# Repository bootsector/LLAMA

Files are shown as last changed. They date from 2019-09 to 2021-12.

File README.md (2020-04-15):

**LLAMA - Low Lag Amazing MiSTer Adapter**

This is an open-source / open-hardware controllers adapter for MiSTer FPGA.

Supported outputs are both USB (XInput) and MiSTer's [LLAPI](https://github.com/Kitrinx/LLAPI/blob/master/LLIO.sv) interface.

32U4 module designs include gerber files and SeeedStudio BOM file for Fusion
PCB Assembly service.

LLAMA currently supports original controllers for the systems below:

- Neo Geo / Neo Geo CD (**NOT compatible with SuperGun DB15 based controllers** )
- Super NES
- NES
- TurboGrafx-16 / PC Engine
- Sega Saturn
- Sega Genesis / Master System / Atari 2600 and compatibles

**Latency Measurements - 1000Hz USB polling mode**
| Controller | Samples | Average | Max | Min | Std Dev |
| --- | --- | --- | ---| ----- | --- |
| LLAMA USB  | 2000 |1.6996ms |2.224ms  |1.188ms| 0.289ms

**Button Mapping**

It's possible to map buttons for each supported joystick. Button mapping is done
based on an index that maps to buttons of the internal abstract pad 
(XInput-like).

Mapping is fully customized by the user. Planning your mapping can be done with
the help of the mapper/LLAMA Mapping.xlsx spreadsheet. Change the buttons of
the supported pads in the "Input" area by selecting them from list boxes. You
can see how those mappings affect output for XInput (USB) and also LLAPI cores
by checking the "Output" area of the spreadsheet.

After setting the mappings in the spreadsheet, simply use the numbers inside
parenthesis for each button of each controller in the ```<profile>``` section of
the mapper/map.xml file. There are two profiles per controller. You just
apply the numbers at the same order they read from the spreadsheet to the
chosen controller profile.

After finishing the changes inside mapper/map.xml file, run the 
mapper/mapper.py application (tested only on Python 2.7). 

```
cd mapper
python mapper.py
```

You should probably
need to install intelhex package via pip beforehand.

```pip install intelhex```

The above will convert map.xml to a file named map.eep. This should be 
flashed into AVR's EEPROM like this:

```dfu-programmer atmega32u4 flash --eeprom map.eep --force```

Mapping is not mandatory. The firmware will save the defaults to EEPROM by
itself the first time it runs if no valid mapping/config is found.

Each controller has two mapping profiles. Below you can find the button
combination on each controller that will switch mapping profiles:

NeoGeo: Down + Start + B

NES: Down + Start + A

SNES: Down + Start + A

Saturn: Down + Start + C

TG16/PCE: Down + Start + I

Genesis: Down + Start + C

**Licensing:**

- Firmware and bootloader sources are licensed under [GPL-3.0](LICENSE)
- PCBs are licensed under [CC BY-NC-SA 4.0](pcb/LICENSE.txt)

**Disclaimer:**

The firmware source code made available here is an original creation by Bruno 
Freitas. 

The AVR ASM/C implementation of the LLAPI "slave" interface presented here
was created from scratch by Bruno Freitas. MiSTer's LLAPI "master" interface
protocol described [here](https://github.com/Kitrinx/LLAPI/blob/master/LLIO.sv) 
in SystemVerilog has been used as documentation and reference only.

No source code from third parties has been used used by this project.

No reverse-engineering has been done against commercial and non-commercial
products during the development of this project.

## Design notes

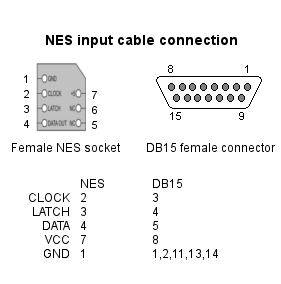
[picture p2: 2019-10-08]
docs/cables/nes.png

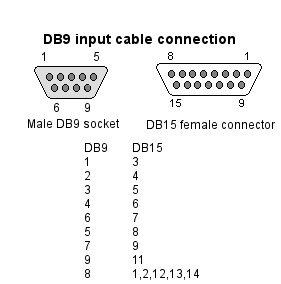
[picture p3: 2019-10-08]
docs/cables/db9.png

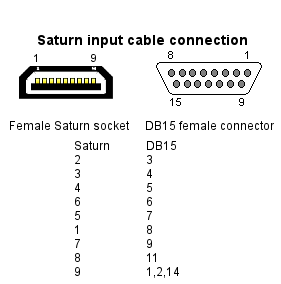
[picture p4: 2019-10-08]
docs/cables/saturn.png

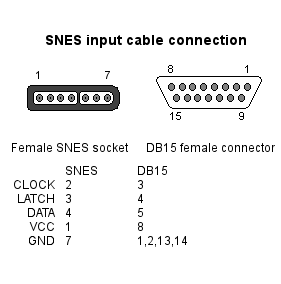
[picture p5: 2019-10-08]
docs/cables/snes.png

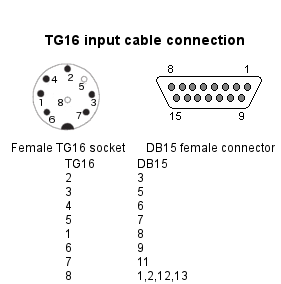
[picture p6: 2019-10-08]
docs/cables/tg16.png

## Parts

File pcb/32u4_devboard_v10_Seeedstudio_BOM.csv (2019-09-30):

Parts | OPL SKU | Qty
C1,C6,C7,C9 | 302010165 | 4
R1,R5 | 301010361 | 2
C8 | 302020011 | 1
XTAL | 306010037 | 1
C2,C3 | 302010143 | 2
R4 | 301010311 | 1
C4 | 302010179 | 1
R2,R3 | 301010329 | 2
32U4-AU | 310010010 | 1
F1 | 307010002 | 1
Led | 304090046 | 1
USB | 320010014 | 1

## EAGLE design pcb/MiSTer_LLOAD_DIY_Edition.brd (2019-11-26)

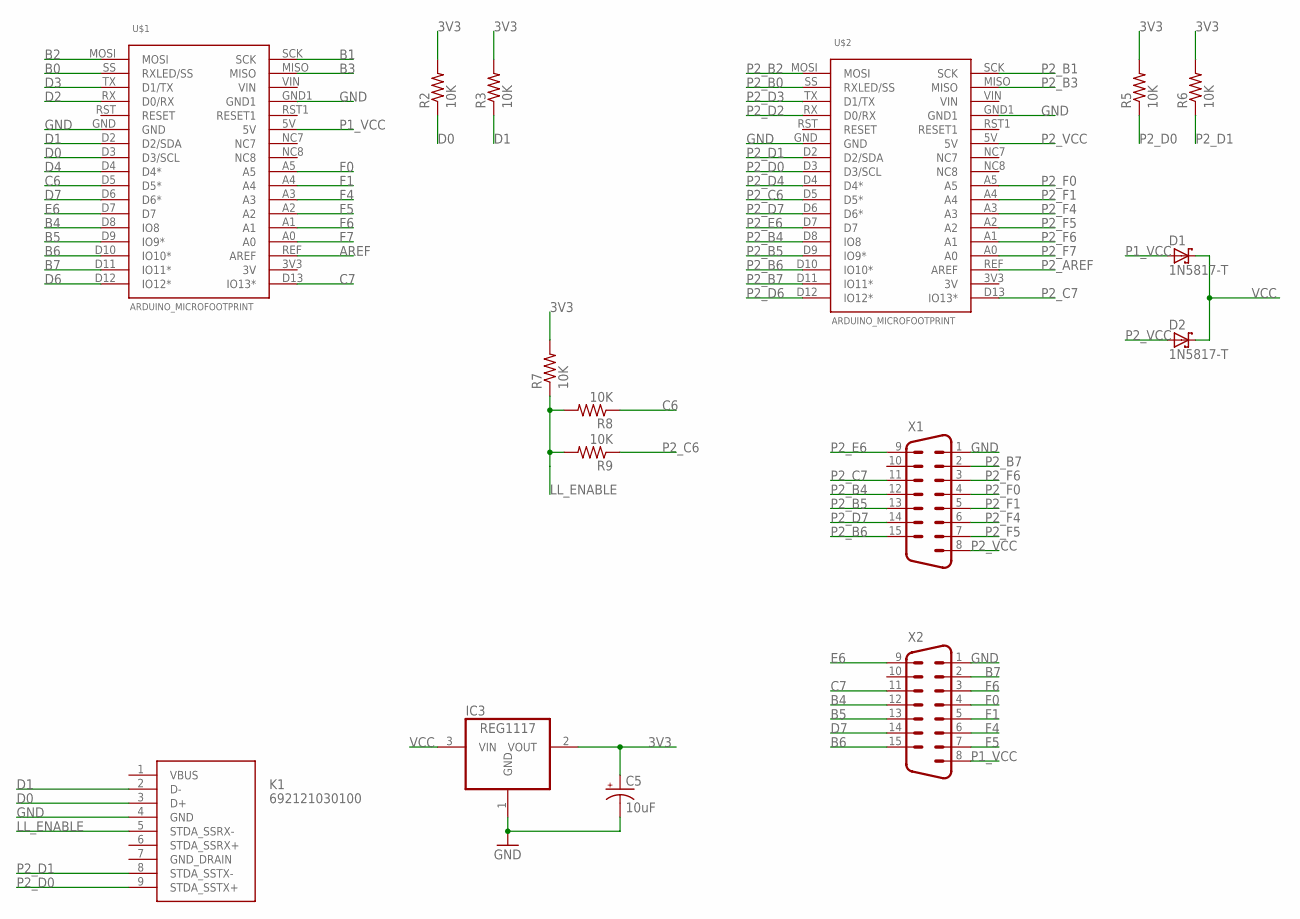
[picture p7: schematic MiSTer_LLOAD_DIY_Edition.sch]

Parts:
C5: 10uF; E2,5-6
D1, D2: 1N5817-T; DO41-7.6
IC3: REG1117; SOT223
K1: 692121030100
R2, R3, R5, R6, R7, R8, R9: 10K; 0207/10
U$1, U$2: ARDUINO_MICROFOOTPRINT; ARDUINO-MICRO
X1, X2: M15HP

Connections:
3V3: C5.+, IC3.2 (VOUT), R2.2, R3.2, R5.2, R6.2, R7.2
AREF: U$1.REF (AREF)
B0: U$1.SS (RXLED/SS)
B1: U$1.SCK
B2: U$1.MOSI
B3: U$1.MISO
B4: U$1.D8 (IO8), X2.12
B5: U$1.D9 (IO9*), X2.13
B6: U$1.D10 (IO10*), X2.15
B7: U$1.D11 (IO11*), X2.2
C6: R8.1, U$1.D5 (D5*)
C7: U$1.D13 (IO13*), X2.11
D0: K1.3 (D+), R2.1, U$1.D3 (D3/SCL)
D1: K1.2 (D-), R3.1, U$1.D2 (D2/SDA)
D2: U$1.RX (D0/RX)
D3: U$1.TX (D1/TX)
D4: U$1.D4 (D4*)
D6: U$1.D12 (IO12*)
D7: U$1.D6 (D6*), X2.14
E6: U$1.D7, X2.9
F0: U$1.A5, X2.4
F1: U$1.A4, X2.5
F4: U$1.A3, X2.6
F5: U$1.A2, X2.7
F6: U$1.A1, X2.3
F7: U$1.A0
GND: C5.-, IC3.1 (GND), K1.4 (GND), U$1.GND, U$1.GND1, U$2.GND, U$2.GND1, X1.1, X2.1
LL_ENABLE: K1.5 (STDA_SSRX-), R7.1, R8.2, R9.2
P1_VCC: D1.A, U$1.5V, X2.8
P2_AREF: U$2.REF (AREF)
P2_B0: U$2.SS (RXLED/SS)
P2_B1: U$2.SCK
P2_B2: U$2.MOSI
P2_B3: U$2.MISO
P2_B4: U$2.D8 (IO8), X1.12
P2_B5: U$2.D9 (IO9*), X1.13
P2_B6: U$2.D10 (IO10*), X1.15
P2_B7: U$2.D11 (IO11*), X1.2
P2_C6: R9.1, U$2.D5 (D5*)
P2_C7: U$2.D13 (IO13*), X1.11
P2_D0: K1.9 (STDA_SSTX+), R5.1, U$2.D3 (D3/SCL)
P2_D1: K1.8 (STDA_SSTX-), R6.1, U$2.D2 (D2/SDA)
P2_D2: U$2.RX (D0/RX)
P2_D3: U$2.TX (D1/TX)
P2_D4: U$2.D4 (D4*)
P2_D6: U$2.D12 (IO12*)
P2_D7: U$2.D6 (D6*), X1.14
P2_E6: U$2.D7, X1.9
P2_F0: U$2.A5, X1.4
P2_F1: U$2.A4, X1.5
P2_F4: U$2.A3, X1.6
P2_F5: U$2.A2, X1.7
P2_F6: U$2.A1, X1.3
P2_F7: U$2.A0
P2_VCC: D2.A, U$2.5V, X1.8
VCC: D1.C, D2.C, IC3.3 (VIN)

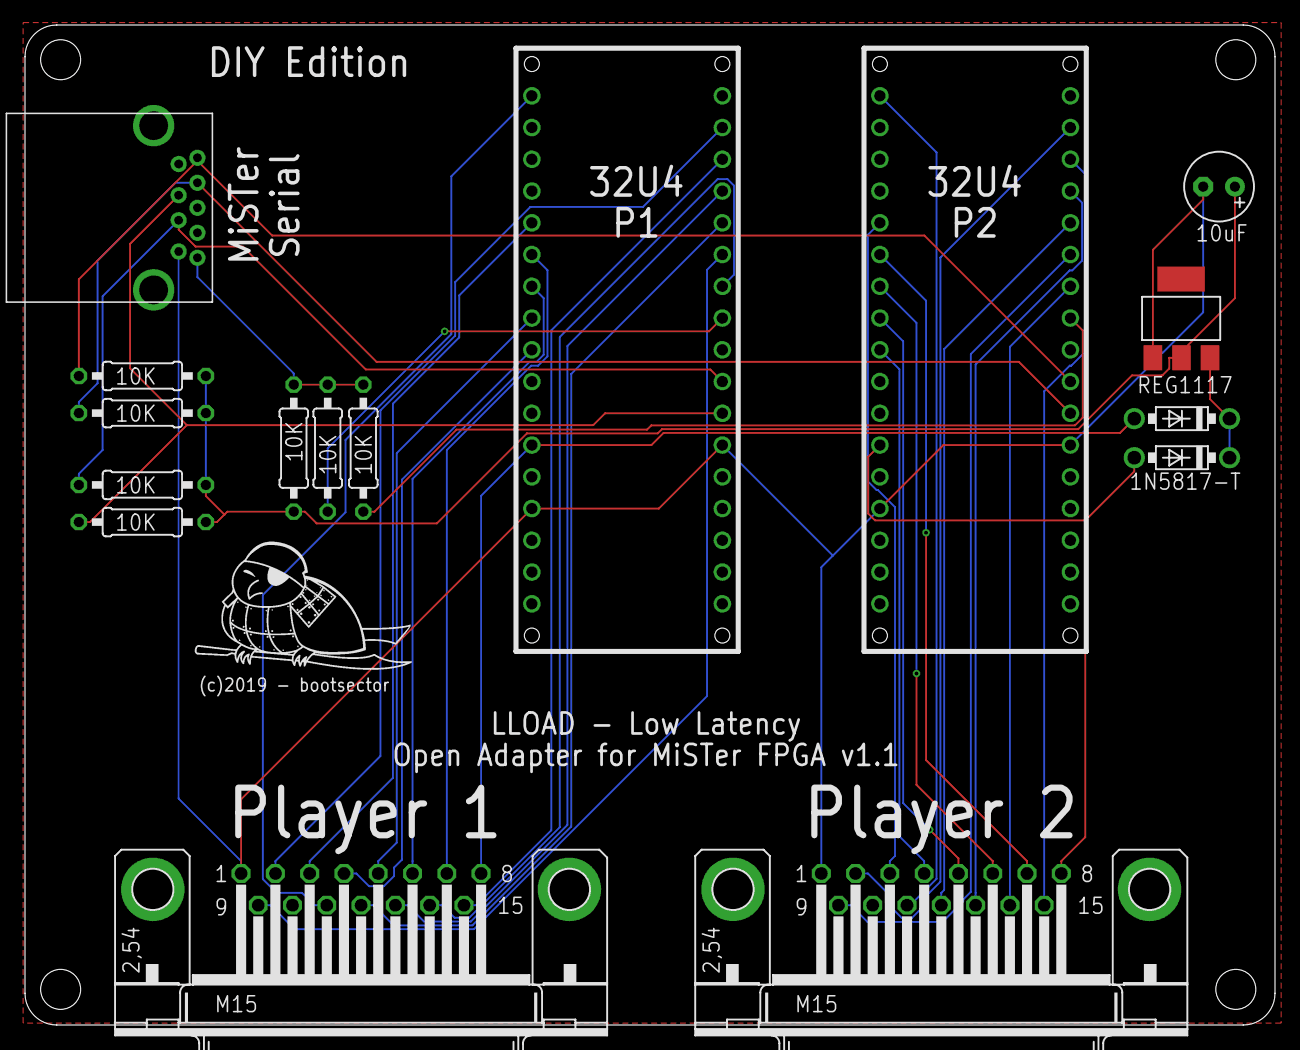
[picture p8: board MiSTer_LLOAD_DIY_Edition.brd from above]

Board: 2 copper layers, 100.0 x 80.0 mm, 16 parts (0 on the bottom side), 36 nets.

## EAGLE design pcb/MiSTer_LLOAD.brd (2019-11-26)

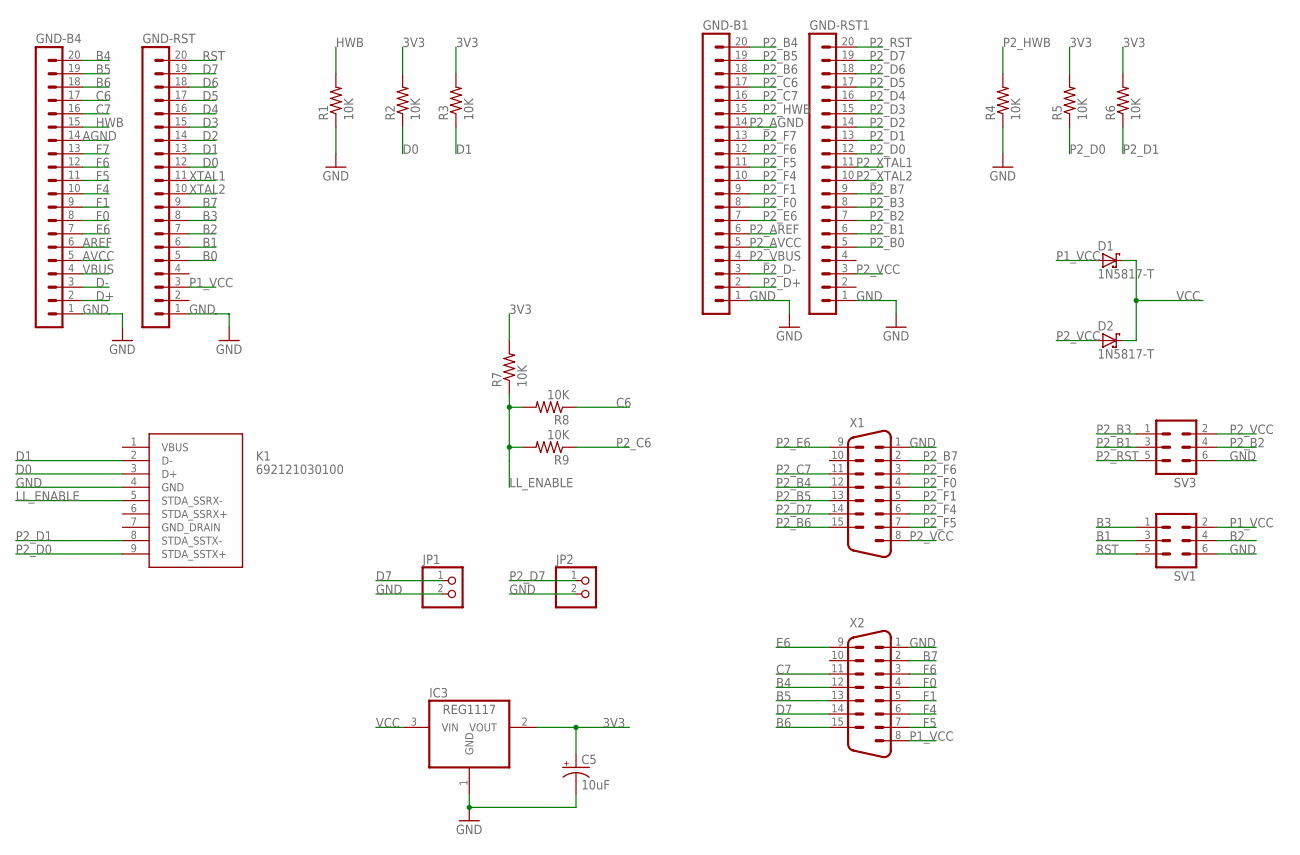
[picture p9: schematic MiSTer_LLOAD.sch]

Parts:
C5: 10uF; E2,5-6
D1, D2: 1N5817-T; DO41-7.6
GND-B1, GND-B4: MA20-1
GND-RST, GND-RST1: MA20-1
IC3: REG1117; SOT223
JP1, JP2: PINHD-1X2; 1X02
K1: 692121030100
R1, R2, R3, R4, R5, R6, R7, R8, R9: 10K; 0207/10
SV1, SV3: MA03-2
X1, X2: M15HP

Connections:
3V3: C5.+, IC3.2 (VOUT), R2.2, R3.2, R5.2, R6.2, R7.2
AGND: GND-B4.14
AREF: GND-B4.6
AVCC: GND-B4.5
B0: GND-RST.5
B1: GND-RST.6, SV1.3
B2: GND-RST.7, SV1.4
B3: GND-RST.8, SV1.1
B4: GND-B4.20, X2.12
B5: GND-B4.19, X2.13
B6: GND-B4.18, X2.15
B7: GND-RST.9, X2.2
C6: GND-B4.17, R8.1
C7: GND-B4.16, X2.11
D0: GND-RST.12, K1.3 (D+), R2.1
D1: GND-RST.13, K1.2 (D-), R3.1
D2: GND-RST.14
D3: GND-RST.15
D4: GND-RST.16
D5: GND-RST.17
D6: GND-RST.18
D7: GND-RST.19, JP1.1, X2.14
D+: GND-B4.2
D-: GND-B4.3
E6: GND-B4.7, X2.9
F0: GND-B4.8, X2.4
F1: GND-B4.9, X2.5
F4: GND-B4.10, X2.6
F5: GND-B4.11, X2.7
F6: GND-B4.12, X2.3
F7: GND-B4.13
GND: C5.-, GND-B1.1, GND-B4.1, GND-RST.1, GND-RST1.1, IC3.1 (GND), JP1.2, JP2.2, K1.4 (GND), R1.1, R4.1, SV1.6, SV3.6, X1.1, X2.1
HWB: GND-B4.15, R1.2
LL_ENABLE: K1.5 (STDA_SSRX-), R7.1, R8.2, R9.2
P1_VCC: D1.A, GND-RST.3, SV1.2, X2.8
P2_AGND: GND-B1.14
P2_AREF: GND-B1.6
P2_AVCC: GND-B1.5
P2_B0: GND-RST1.5
P2_B1: GND-RST1.6, SV3.3
P2_B2: GND-RST1.7, SV3.4
P2_B3: GND-RST1.8, SV3.1
P2_B4: GND-B1.20, X1.12
P2_B5: GND-B1.19, X1.13
P2_B6: GND-B1.18, X1.15
P2_B7: GND-RST1.9, X1.2
P2_C6: GND-B1.17, R9.1
P2_C7: GND-B1.16, X1.11
P2_D0: GND-RST1.12, K1.9 (STDA_SSTX+), R5.1
P2_D1: GND-RST1.13, K1.8 (STDA_SSTX-), R6.1
P2_D2: GND-RST1.14
P2_D3: GND-RST1.15
P2_D4: GND-RST1.16
P2_D5: GND-RST1.17
P2_D6: GND-RST1.18
P2_D7: GND-RST1.19, JP2.1, X1.14
P2_D+: GND-B1.2
P2_D-: GND-B1.3
P2_E6: GND-B1.7, X1.9
P2_F0: GND-B1.8, X1.4
P2_F1: GND-B1.9, X1.5
P2_F4: GND-B1.10, X1.6
P2_F5: GND-B1.11, X1.7
P2_F6: GND-B1.12, X1.3
P2_F7: GND-B1.13
P2_HWB: GND-B1.15, R4.2
P2_RST: GND-RST1.20, SV3.5
P2_VBUS: GND-B1.4
P2_VCC: D2.A, GND-RST1.3, SV3.2, X1.8
P2_XTAL1: GND-RST1.11
P2_XTAL2: GND-RST1.10
RST: GND-RST.20, SV1.5
VBUS: GND-B4.4
VCC: D1.C, D2.C, IC3.3 (VIN)
XTAL1: GND-RST.11
XTAL2: GND-RST.10

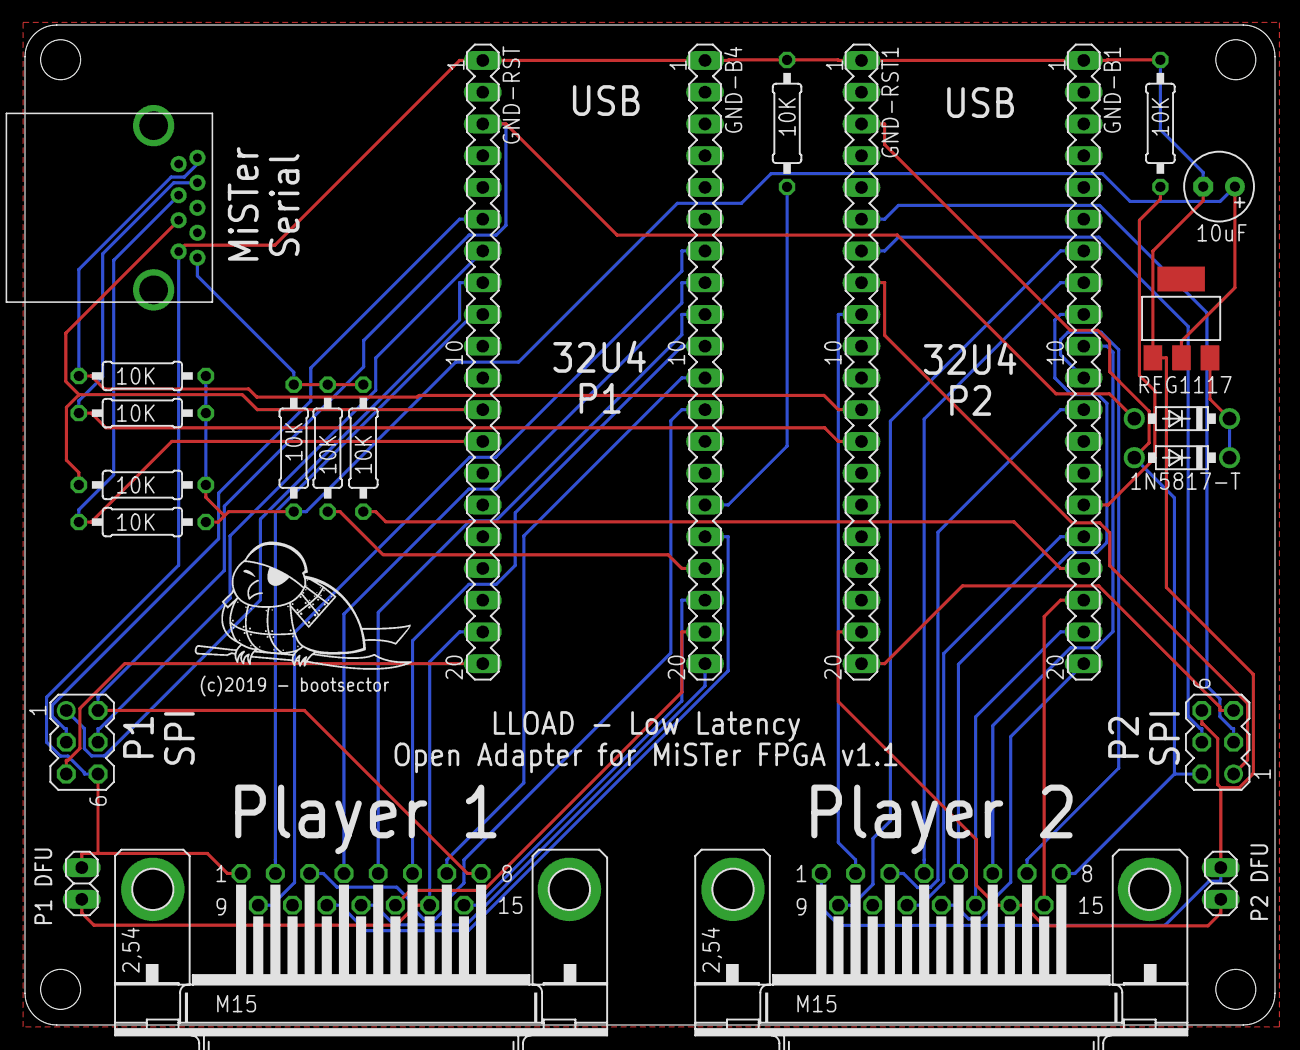
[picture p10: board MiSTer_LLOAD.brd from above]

Board: 2 copper layers, 100.0 x 80.0 mm, 24 parts (0 on the bottom side), 46 nets.

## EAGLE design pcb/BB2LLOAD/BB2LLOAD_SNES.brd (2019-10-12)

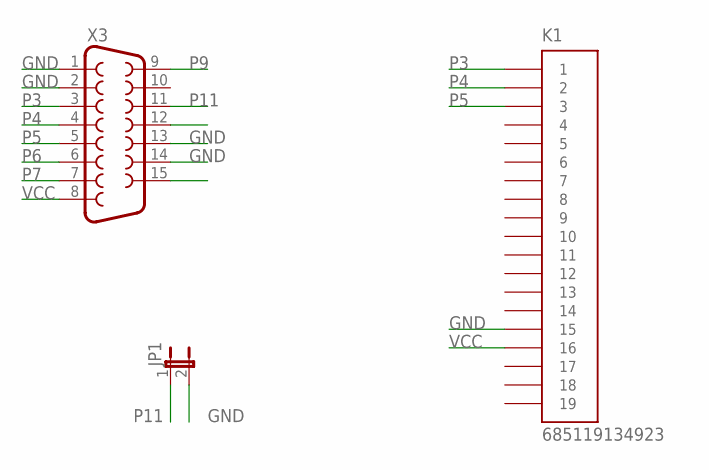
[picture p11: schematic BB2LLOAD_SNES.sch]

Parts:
JP1: JP1E; JP1
K1: 685119134923
X3: F15HP

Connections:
GND: JP1.2, K1.15, X3.1, X3.2, X3.13, X3.14
P3: K1.1, X3.3
P4: K1.2, X3.4
P5: K1.3, X3.5
P6: X3.6
P7: X3.7
P9: X3.9
P11: JP1.1, X3.11
VCC: K1.16, X3.8

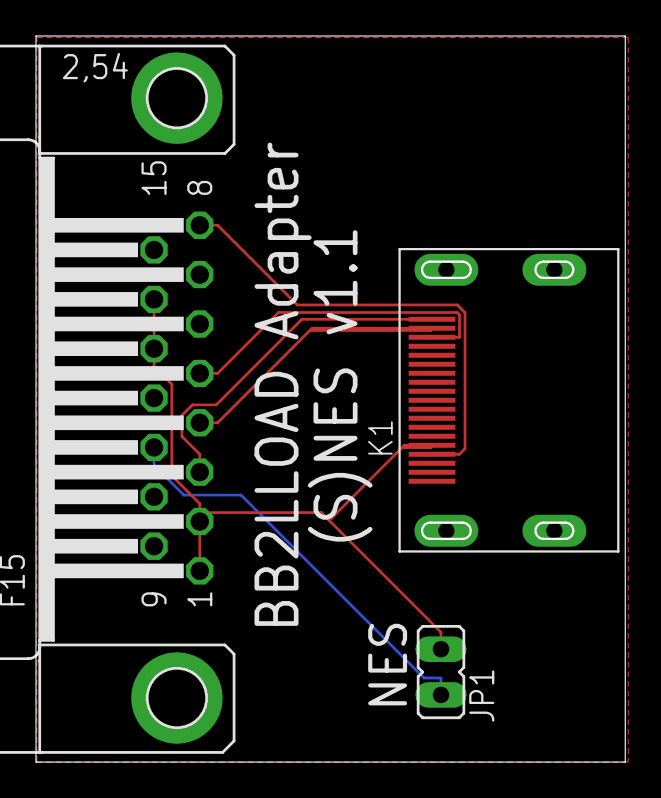
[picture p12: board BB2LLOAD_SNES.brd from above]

Board: 2 copper layers, 32.7 x 40.3 mm, 3 parts (0 on the bottom side), 6 nets.

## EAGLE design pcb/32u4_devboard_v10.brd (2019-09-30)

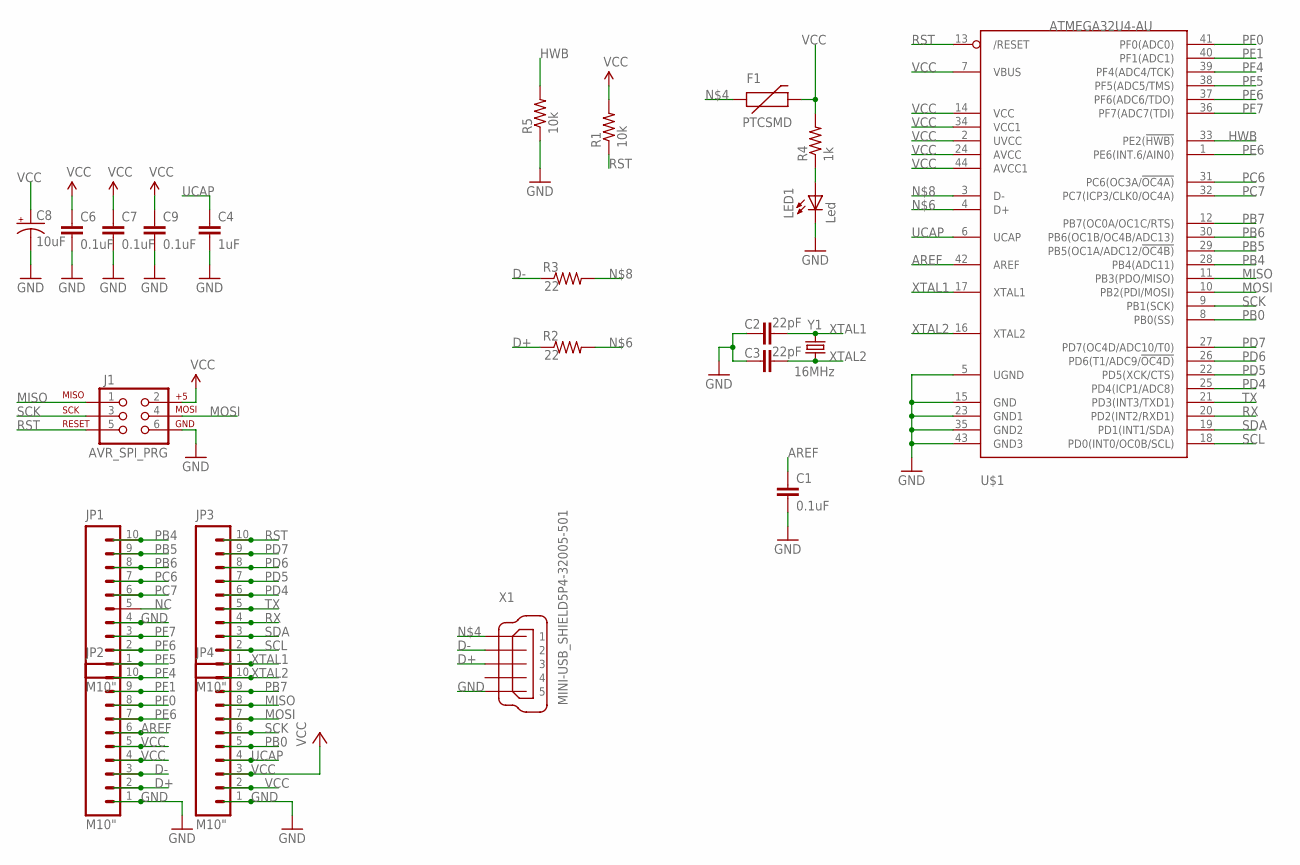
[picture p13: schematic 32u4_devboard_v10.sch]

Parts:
C1, C6, C7, C9: 0.1uF; 0805
C2, C3: 22pF; 0603-CAP
C4: 1uF; 0805
C8: 10uF; EIA3216
F1: PTCSMD; PTC-1206
J1: AVR_SPI_PRG; 2X3
JP1, JP2, JP3, JP4: M10"; 1X10
LED1: Led; CHIP-LED0805
R1, R5: 10k; 0805
R2, R3: 22; 0805
R4: 1k; 0805
U$1: ATMEGA32U4-AU; TQFP44
X1: MINI-USB_SHIELD5P4-32005-501; 32005-501
Y1: 16MHz; HC49US

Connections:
AREF: C1.1, JP2.6, U$1.42 (AREF)
D+: JP2.2, R2.1, X1.3
D-: JP2.3, R3.1, X1.2
GND: C1.2, C2.1, C3.1, C4.2, C6.2, C7.2, C8.C (-), C9.2, J1.6, JP1.4, JP2.1, JP4.1, LED1.C, R5.1, U$1.5 (UGND), U$1.15 (GND), U$1.23 (GND1), U$1.35 (GND2), U$1.43 (GND3), X1.5
HWB: R5.2, U$1.33 (PE2(!HWB))
MISO: J1.1, JP4.8, U$1.11 (PB3(PDO/MISO))
MOSI: J1.4, JP4.7, U$1.10 (PB2(PDI/MOSI))
unnamed: F1.1, X1.1
unnamed: R2.2, U$1.4 (D+)
unnamed: R3.2, U$1.3 (D-)
unnamed: LED1.A, R4.1
NC: JP1.5
PB0: JP4.5, U$1.8 (PB0(SS))
PB4: JP1.10, U$1.28 (PB4(ADC11))
PB5: JP1.9, U$1.29 (PB5(OC1A/ADC12/!OC4B))
PB6: JP1.8, U$1.30 (PB6(OC1B/OC4B/ADC13))
PB7: JP4.9, U$1.12 (PB7(OC0A/OC1C/RTS))
PC6: JP1.7, U$1.31 (PC6(OC3A/!OC4A))
PC7: JP1.6, U$1.32 (PC7(ICP3/CLK0/OC4A))
PD4: JP3.6, U$1.25 (PD4(ICP1/ADC8))
PD5: JP3.7, U$1.22 (PD5(XCK/CTS))
PD6: JP3.8, U$1.26 (PD6(T1/ADC9/!OC4D))
PD7: JP3.9, U$1.27 (PD7(OC4D/ADC10/T0))
PE6: JP2.7, U$1.1 (PE6(INT.6/AIN0))
PF0: JP2.8, U$1.41 (PF0(ADC0))
PF1: JP2.9, U$1.40 (PF1(ADC1))
PF4: JP2.10, U$1.39 (PF4(ADC4/TCK))
PF5: JP1.1, U$1.38 (PF5(ADC5/TMS))
PF6: JP1.2, U$1.37 (PF6(ADC6/TDO))
PF7: JP1.3, U$1.36 (PF7(ADC7(TDI))
RST: J1.5, JP3.10, R1.1, U$1.13 (/RESET)
RX: JP3.4, U$1.20 (PD2(INT2/RXD1))
SCK: J1.3, JP4.6, U$1.9 (PB1(SCK))
SCL: JP3.2, U$1.18 (PD0(INT0/OC0B/SCL))
SDA: JP3.3, U$1.19 (PD1(INT1/SDA))
TX: JP3.5, U$1.21 (PD3(INT3/TXD1))
UCAP: C4.1, JP4.4, U$1.6 (UCAP)
VCC: C6.1, C7.1, C8.A (+), C9.1, F1.2, J1.2, JP2.4, JP2.5, JP4.2, JP4.3, R1.2, R4.2, U$1.2 (UVCC), U$1.7 (VBUS), U$1.14 (VCC), U$1.24 (AVCC), U$1.34 (VCC1), U$1.44 (AVCC1)
XTAL1: C2.2, JP3.1, U$1.17 (XTAL1), Y1.2
XTAL2: C3.2, JP4.10, U$1.16 (XTAL2), Y1.1

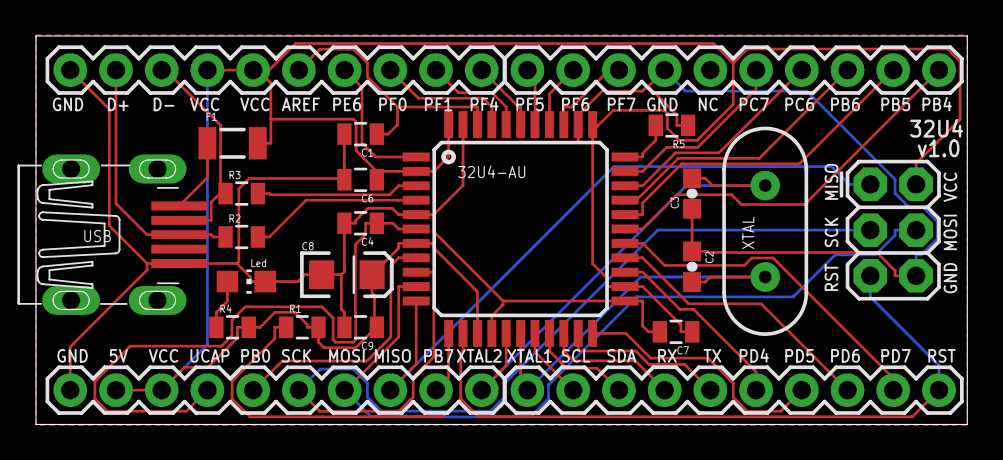
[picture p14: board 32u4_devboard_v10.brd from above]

Board: 2 copper layers, 51.7 x 21.6 mm, 23 parts (0 on the bottom side), 39 nets.

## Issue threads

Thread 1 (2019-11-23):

Supergun pinout risk.

Dubon77, 2019-11-23:
Currently connecting a controller that is wired for connecting to a supergun can not be directly connected to the db15 port and requires an adapter. Neo geo controllers should be fine. This is , afaik, because pin 10 currently is powered and pressing a button connected to it could cause damage to the arduino. Because of this either an adapter, or a revision of the main pcb witch fixes this is required.

bootsector, 2019-11-26:
Pushed new v1.1 revision. This is still not compatible with Supergun (although it still works with Neo Geo and Neo Geo CD pads, just like the previous version). I will work on a PCB adapter to allow supergun on this soon.

Closed 2019-11-26.

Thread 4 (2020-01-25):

All controller types share the same USB PID

mathieulh, 2020-01-25:
All controller types share the same USB PID, this causes issues when mapping usb controllers on the MiSTer main menu as mapping one controller overwrites the previous mapping of another as all controllers, regardless of types/number of buttons... are detected as the same controller; using a different PID per controller type would fix this.

Here is an example of 2 LLOAD instances using a SATURN and a SNES controller respectively:

[  409.018380] usb 1-1.7: USB disconnect, device number 8
[  748.401583] usb 1-1.7: new full-speed USB device number 9 using dwc2
[  748.505909] usb 1-1.7: New USB device found, idVendor=045e, idProduct=028e, bcdDevice= 1.14
[  748.505969] usb 1-1.7: New USB device strings: Mfr=1, Product=2, SerialNumber=3
[  748.505977] usb 1-1.7: Product: LLOAD - Low Latency Open Adapter
[  748.505984] usb 1-1.7: Manufacturer: www.brunofreitas.com
[  748.505989] usb 1-1.7: SerialNumber: 1.0
[  748.508384] XPAD: original out.bInterval=1 -> new interval=1
[  748.508393] XPAD: original in.bInterval=1 -> new interval=1
[  748.508856] input: Microsoft X-Box 360 pad as /devices/platform/soc/ffb40000.usb/usb1/1-1/1-1.7/1-1.7:1.0/input/input9

[  876.218384] usb 1-1.2: USB disconnect, device number 3
[  877.681857] usb 1-1.2: new full-speed USB device number 10 using dwc2
[  877.783101] usb 1-1.2: New USB device found, idVendor=045e, idProduct=028e, bcdDevice= 1.14
[  877.783112] usb 1-1.2: New USB device strings: Mfr=1, Product=2, SerialNumber=3
[  877.783119] usb 1-1.2: Product: LLOAD - Low Latency Open Adapter
[  877.783126] usb 1-1.2: Manufacturer: www.brunofreitas.com
[  877.783132] usb 1-1.2: SerialNumber: 1.0
[  877.785749] XPAD: original out.bInterval=1 -> new interval=1
[  877.785758] XPAD: original in.bInterval=1 -> new interval=1
[  877.786275] input: Microsoft X-Box 360 pad as /devices/platform/soc/ffb40000.usb/usb1/1-1/1-1.2/1-1.2:1.0/input/input10

The firmware code would need to be adapted to not use the fixed descriptors found here:

https://github.com/bootsector/LLOAD/blob/master/firmware/Output/USB/Descriptors.c

bootsector, 2020-01-25:
What kind of issues are you having with this? This is by design. Changing PID is not ideal since it will require a USB disconnection/connection every time you change controllers. This is something I don't want LLOAD to have.

mathieulh, 2020-01-26:
The main issue is that MiSTer OSD uses PID to differentiate between controllers, so if you use a genesis  or saturn 6 button controller, map the controls on the MiSTer main menu, then use a SNES controller and map the controls again, finally switch back to your genesis/saturn controllers, buttons used in the OSD won't be the same because the remapping of your SNES controller will have overwritten the mapping configuration for your Genesis/Saturn one.

bootsector, 2020-01-26:
For that you should rely on LLOAD's own pad abstraction default mapping. So, for example, if you map SNES buttons B and A for CANCEL and ENTER respectively, those will be B and C on a Saturn pad (and B and A for a NES pad, and A and B for a NeoGeo CD pad, and so on...)

mathieulh, 2020-01-26:
That's pretty much what I am doing but it is both kind of confusing and annoying, especially to average users who wouldn't understand why their controller configurations keep changing, realistically resetting the usb stack after controller detection would take less than a second and likely be imperceptible to the end user.

bootsector, 2020-02-08:
As discussed previously, I'm closing this because:

1- This behavior is by design

2- LLOAD is a unique USB device. Hence it should have a single VID:PID as per standard

3- There's no "clean" way to change the PID. Also, Windows has issues with some PIDs not issued by Microsoft.

Closed 2020-02-08.

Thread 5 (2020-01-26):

Feature Request:  Ability to rotate button mapping

SegaSnatcher, 2020-01-26:
There is a handy feature within Gamer Pro/Blisster where you can hold 4 face buttons + start and it will rotate the controller mapping.   So say you want to use a SNES controller on GBA core via LLAPI, but don't like having to use the B and A buttons, you simply hold 4 buttons + Start for a few seconds and it will rotate the mapping so that Y functions as the B button and B functions as the A button.  This makes playing GBA with a SNES controller much more enjoyable.

bootsector, 2020-01-26:
In order to keep consistency with what MiSTer already provides for USB controllers, best approach would be adding mapping capabilities inside LLAPI cores. More logic added to the controller adapter, more lag we get.
In case LLAPI input mapping is not under anyone's roadmap, I will think about some simple input profiles switching in the future. No ETA on this, though.

bootsector, 2020-02-14:
No mapping is planned for LLAPI. Actually, LLAPI support should be completely removed in the near future since it's not MiSTer official.

Closed 2020-02-14.

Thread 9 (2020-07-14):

PCE 6 buttons pad issue

sk8er000, 2020-07-14:
I've made 2 cable adapter for PC-Engine following the schemes. If I use a regular 2 buttons pad thy work wih no issue but if I try to use a 6 buttons pad (I've tested the one that came with the PC-Duo RX) it detects the UP and LEFT directions always pressed.
If I use the pad on the PC-Duo RX, PCE or Supergrafx it works

bootsector, 2020-07-14:
Could you please test with the attached firmware and let me know the results?
[LLAMA.hex.zip](https://github.com/bootsector/LLAMA/files/4917843/LLAMA.hex.zip)

sk8er000, 2020-07-14:
Is there a suggested update procedure?

bootsector, 2020-07-14:
Are you using the DIY version with the Arduino Leonardo?

sk8er000, 2020-07-14:
I'm using the version assembled by Bruno Freitas

bootsector, 2020-07-14:
That would be me! :)

What operating system are you using so I can give you the right steps?

sk8er000, 2020-07-14:
Didn't know that :D
I mainly use Windows 10 but I can use other OS if needed

bootsector, 2020-07-14:
1 - Install the DFU driver by right clicking the dpinst64.exe installer in the drivers directory of the attached zip and running as admin  (assuming you have a 64bit Windows OS).

2 - Connect the P1 DFU jumper and connect the P1 USB to your PC via USB

3 - Double click the flash.bat file for updating the firmware.

4 - Repeat 2 and 3 for updating the second port

Let me know how it goes!

[flash.zip](https://github.com/bootsector/LLAMA/files/4918518/flash.zip)

sk8er000, 2020-07-14:
Thank you for the guide.
I've flashed the new fw!
Now the up direction works fine but the left direction is still pressed. If I press the right direction on the test pad ROM the left direction is not pressed anymore but neither the right direction.
The 2 buttons pad is still working with no issues

bootsector, 2020-07-14:
Aside of the left direction being pressed, all the other buttons work correctly?

sk8er000, 2020-07-14:
Yes they're working fine but I've discovered a strange behaviour:
-Actually I have the P1 with new fw and P2 with the old one
- 2 buttons controller works on both
- 6 buttons controller on older fw detects up and left always pressed on new one only left (all other signal are working, up direction is working only on the new fw)
- if I loose very much (untill they're barely connected) the connection between the adaptor and the pad on both firmwares everything is working.

Tested with 2 different pads and 2 different adapters

bootsector, 2020-07-14:
Hmm... That's a really odd behavior. It's leaning to a bad connection somewhere. Only change from original fw to the new one I've sent you for testing is decreasing the frequency we talk to the controller. I'm attaching here a new hex so you can flash and test (now with an even slower frequency)
[LLAMA.hex.zip](https://github.com/bootsector/LLAMA/files/4918812/LLAMA.hex.zip)

sk8er000, 2020-07-14:
It's still working in the same way.
The strange thing is that there are no issue with the regular pad on the direction and that the UP direction was fixed by the firmware otherwise the issue was obviously related to the wiring.
Since on the github there is only the scheme for the TG16 port adapter I've used a second scheme to traspose the TG16 signal to the PCE ones:
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

bootsector, 2020-07-14:
Could you please give it a try with this one and let me know?
[LLAMA.hex.zip](https://github.com/bootsector/LLAMA/files/4918953/LLAMA.hex.zip)

sk8er000, 2020-07-14:
Now both models (2 and 6 buttons) are working with no issues!

sk8er000, 2020-07-14:
Edit
Sometimes the left button is detected even if not pressed but is mainly working

bootsector, 2020-07-14:
Just pushed this commig: https://github.com/bootsector/LLAMA/commit/6a01088b381b4b94614d69b81a3c75c0e6b575ef

I think there's something odd with the pullup resistor connected to your 6 button controller's left button.

bootsector, 2020-07-14:
This is the latest commit but I've increased the delay from 20us to 40us. Could you please check if left button is still flaky?
[LLAMA.hex.zip](https://github.com/bootsector/LLAMA/files/4919028/LLAMA.hex.zip)

sk8er000, 2020-07-14:
It seems to work, I'm sorry for all the trouble, unfortunately I've got only 2 6 buttons pad that were bundled with my pc duo Rx and I don't have other 6 buttons pad to test. This models are considered to have a clunky dpad, I'll try to open and inspect them but now it's much better than before! Thank you

bootsector, 2020-07-14:
No problem. Let's keep this issue opened until we get this 100% figured out. Does it work better with latest zip or same thing as the previous one?

sk8er000, 2020-07-14:
Now it's working a lot better sometimes if I hold firmly right it's been detected like if it's an autofire button (it's repeatedly pressed very fast instead of being firmly pressed). But it seems a pad issue rather than a fw issue (I'll check it soon).
Tested other 4 original pce 2 buttons pad (various models) and everyone is working properly.

bootsector, 2020-07-14:
I think that it could be a good idea to check if the VCC on your DIN/mini-DIN connectors are really giving out 5V too.

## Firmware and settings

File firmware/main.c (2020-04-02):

/*
* LLAMA - Low Lag Amazing MiSTer Adapter
*
* Copyright (c) 2019
* Bruno Freitas - bruno@brunofreitas.com - http://www.brunofreitas.com/
*
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
* You should have received a copy of the GNU General Public License
* along with this program. If not, see <http://www.gnu.org/licenses/>.
*/

#include <avr/io.h>

#include "Input.h"
#include "Output.h"
#include "Util.h"
#include "Config.h"
#include "Mapper.h"

AbstractPad_t PadData_DB15, PadData_Output;

void LLOAD_PadReadCallback(void) {
	Input_GetPadState(&PadData_DB15);
	Mapper_Map();
}

int main(void) {

	// Set clock @ 16Mhz
	CPU_PRESCALE(0);

	// Disable JTAG
	bit_set(MCUCR, 1 << JTD);
	bit_set(MCUCR, 1 << JTD);

	// Load map config
	LLOADConfig_Init();

	// Reset pad data buffers
	AbstractPad_ResetBuffer(&PadData_DB15);
	AbstractPad_ResetBuffer(&PadData_Output);

	// Initialize LLIO and USB interfaces
	Output_Init();

	// Set synchronous pad reading callback for LLIO
	Output_SetLLIOCallback(LLOAD_PadReadCallback);

	// Initialize DB15 interface
	Input_Init();

	// Initialize pad mapping engine
	Mapper_Init(&PadData_DB15, &PadData_Output);

	// Main loop
	for (;;) {
		if (!Output_LLEnabled()) {
			LLOAD_PadReadCallback();
		}

		Output_SetPadState(&PadData_Output);
	}
}

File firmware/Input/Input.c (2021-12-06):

/*
* LLAMA - Low Lag Amazing MiSTer Adapter
*
* Copyright (c) 2019
* Bruno Freitas - bruno@brunofreitas.com - http://www.brunofreitas.com/
*
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
* You should have received a copy of the GNU General Public License
* along with this program. If not, see <http://www.gnu.org/licenses/>.
*/

#include <avr/io.h>
#include <util/delay.h>
#include <avr/interrupt.h>

#include "Input.h"
#include "Util.h"
#include "Config.h"

#include "NeoGeo_In.h"
#include "SNES_In.h"
#include "Genesis_In.h"
#include "TG16_In.h"
#include "Saturn_In.h"

static volatile uint8_t current_pad = DB15_PAD_NEOGEO;
static volatile uint8_t needs_detection = 0;
static volatile uint8_t detection_timeout = 0;
static volatile uint8_t needs_status_clear = 0;
static volatile uint8_t pad_initialized = 0;

static void Input_InitPort(void) {
	// DB15_3
	bit_clear(DDRF, 1 << 6);
	bit_set(PORTF, 1 << 6);

	// DB15_4
	bit_clear(DDRF, 1 << 0);
	bit_set(PORTF, 1 << 0);

	// DB15_5
	bit_clear(DDRF, 1 << 1);
	bit_set(PORTF, 1 << 1);

	// DB15_6
	bit_clear(DDRF, 1 << 4);
	bit_set(PORTF, 1 << 4);

	// DB15_7
	bit_clear(DDRF, 1 << 5);
	bit_set(PORTF, 1 << 5);

	// DB15_9
	bit_clear(DDRE, 1 << 6);
	bit_set(PORTE, 1 << 6);

	// DB15_11
	bit_clear(DDRC, 1 << 7);
	bit_set(PORTC, 1 << 7);

	// DB15_12
	bit_clear(DDRB, 1 << 4);
	bit_set(PORTB, 1 << 4);

	// DB15_13
	bit_clear(DDRB, 1 << 5);
	bit_set(PORTB, 1 << 5);

	// DB15_14
	bit_clear(DDRD, 1 << 7);
	bit_set(PORTD, 1 << 7);

	// DB15_15
	bit_clear(DDRB, 1 << 6);
	bit_set(PORTB, 1 << 6);

	// Disable ADC (if enabled by paddles reading driver)
	ADMUX = ADCSRA = 0;
}

static void Input_InitializePad(uint8_t force_init) {

	if (force_init) {
		pad_initialized = 0;
	}

	if (pad_initialized) {
		return;
	}

	switch (current_pad) {
		case DB15_PAD_NEOGEO:
			pad_initialized = NeoGeo_In_Init();
			break;
		case DB15_PAD_SNES:
		case DB15_PAD_NES:
		case DB15_PAD_SUPERGUN:
			pad_initialized = SNES_In_Init();
			break;
		case DB15_PAD_GENESIS:
			pad_initialized = Genesis_In_Init();
			break;
		case DB15_PAD_TG16:
			pad_initialized = TG16_In_Init();
			break;
		case DB15_PAD_SATURN:
			pad_initialized = Saturn_In_Init();
			break;
		default:
			pad_initialized = NeoGeo_In_Init();
			break;
	}
}

static void Input_ReadPad(AbstractPad_t *padData) {

	if (!pad_initialized) {
		return;
	}

	switch (current_pad) {
		case DB15_PAD_NEOGEO:
			NeoGeo_In_GetPadState(padData);
			padData->cfg_map_pad_id = LLOAD_CFG_PAD_NEOGEO;
			break;
		case DB15_PAD_SNES:
		case DB15_PAD_SUPERGUN:
			SNES_In_GetPadState(padData);
			padData->cfg_map_pad_id = LLOAD_CFG_PAD_SNES;
			break;
		case DB15_PAD_NES:
			NES_In_GetPadState(padData);
			padData->cfg_map_pad_id = LLOAD_CFG_PAD_NES;
			break;
		case DB15_PAD_GENESIS:
			Genesis_In_GetPadState(padData);
			padData->cfg_map_pad_id = LLOAD_CFG_PAD_GENESIS;
			break;
		case DB15_PAD_TG16:
			TG16_In_GetPadState(padData);
			padData->cfg_map_pad_id = LLOAD_CFG_PAD_TG16;
			break;
		case DB15_PAD_SATURN:
			Saturn_In_GetPadState(padData);
			padData->cfg_map_pad_id = LLOAD_CFG_PAD_SATURN;
			break;
		default:
			NeoGeo_In_GetPadState(padData);
			padData->cfg_map_pad_id = LLOAD_CFG_PAD_NEOGEO;
			break;
	}
}

static void Input_DetectPad(void) {
	uint8_t attachedPad;

	// C7 - ID Bit 0 - Input and pull-up ON
	bit_clear(DDRC, 1 << 7);
	bit_set(PORTC, 1 << 7);

	// B4 - ID Bit 1 - Input and pull-up ON
	bit_clear(DDRB, 1 << 4);
	bit_set(PORTB, 1 << 4);

	// B5 - ID Bit 2 - Input and pull-up ON
	bit_clear(DDRB, 1 << 5);
	bit_set(PORTB, 1 << 5);

	// D7 - ID Bit 3 - Input and pull-up ON
	bit_clear(DDRD, 1 << 7);
	bit_set(PORTD, 1 << 7);

	_delay_ms(50);

	attachedPad = (bit_check(PIND, 7) << 3) | (bit_check(PINB, 5) << 2) |
			(bit_check(PINB, 4) << 1) | (bit_check(PINC, 7));

	current_pad = attachedPad;

	Input_InitializePad(1);

	needs_detection = 0;
}

void Input_Init(void) {
	
	Input_InitPort();
	
	current_pad = DB15_PAD_NEOGEO;
	needs_detection = 0;
	detection_timeout = 0;
	pad_initialized = 0;
	needs_status_clear = 0;

	// Setup Auto-Sensing pin - Input Pull-Up ON
	bit_clear(DDRB, 1 << 7);
	bit_set(PORTB, 1 << 7);

	//Pin Change Interrupt Enable for the Auto-Sensing Pin
	PCICR |= (1 << PCIE0);
	PCMSK0 |= (1 << PCINT7);

	Input_DetectPad();
}

void Input_GetPadState(AbstractPad_t *padData) {
	if (needs_status_clear) {
		AbstractPad_ResetBuffer(padData);

		needs_status_clear = 0;

		return;
	}

	if (detection_timeout) {
		_delay_ms(5);

		detection_timeout--;

		return;
	}

	if (needs_detection) {
		Input_DetectPad();
	} else {
		// This will simply return if connected pad is already initialized
		Input_InitializePad(0);
	}

	Input_ReadPad(padData);
}

// DB15 (dis)connect auto-sensing pin ISR
ISR(PCINT0_vect)
{
	Input_InitPort();

	needs_detection = needs_status_clear = 1;

	detection_timeout = 100;
}

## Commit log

2019-10-01 Corrected LLIO data polling pin
2019-10-01 Corrected LLIO polling command
    [LLIO.c]
2019-10-08 Auto input detection framework
2019-10-08 Adding pad reading drivers and input cables schematics
2019-10-09 Talked to Kitrinx and she told me that since I didn't use any portions of her code, I shouldn't add her licensing header. That makes sense to me. Reverting.
    [LLIO.c]
2019-10-12 Adding BB2LLOAD pcb files for Saturn
    [BB2LLOAD_Saturn.brd, BB2LLOAD_Saturn.sch]
2019-10-12 Changed form factor of the bb2load pcb (slim)
    [BB2LLOAD_Saturn.brd]
2019-10-12 Adding bb2lload pcbs for (s)nes cables.
    [BB2LLOAD_SNES.brd, BB2LLOAD_SNES.sch]
2019-10-12 Adding bb2lload pcbs for TG16 cables.
    [BB2LLOAD_TG16.brd, BB2LLOAD_TG16.sch]
2019-10-12 Adding DB9 to DB15 adapter pcb files
    [LLOAD_DB9_Adapter.brd, LLOAD_DB9_Adapter.sch]
2019-10-12 LL detection pin setup fix
    [LLIO.c]
2019-10-12 LLIO response to cmd 0x00 fix
    [LLIO.c]
2019-10-13 Fixing DB9 adapter ID bits
    [Genesis_In.c]
2019-10-14 Proto v0.3 PCB - It does not rely on Serial IO VCC anymore
    [MiSTer_LLOAD.brd, MiSTer_LLOAD.sch]
2019-10-15 LLIO timing calibration
2019-10-16 Promoting LLOAD PCB to v1.0
    [MiSTer_LLOAD.brd, MiSTer_LLOAD.sch]
2019-10-17 Optimizing output buffers clear: Now it happens only during output mode switches (LL/USB)
2019-10-17 Added DIY (Arduino Micro based) PCB edition. Untested!
    [MiSTer_LLOAD_DIY_Edition.brd, MiSTer_LLOAD_DIY_Edition.sch]
2019-10-29 Changing CALL to RCALL - AVR assembler is already doing this as part of -mrelax flag
2019-11-06 Undefining USB device serial number so MiSTer does not get crazy
2019-11-06 Revert "Undefining USB device serial number so MiSTer does not get crazy"
    This reverts commit 8516f9a6f194a1c2c52c805fb26148e81404ed00.
2019-11-06 Adding acrilic case cut fie
2019-11-26 Removed alternate VCC (3.3v) from DB15 pin 10. This will not make it directly compatible with supergun input, but at least no harm will be done in case someone inadvertently uses a supergun with it. 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
    [MiSTer_LLOAD.brd, MiSTer_LLOAD.sch, MiSTer_LLOAD_DIY_Edition.brd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]
2020-02-13 Reporting correct pad id to LLAPI host
    [Genesis_In.c, LLIO.c, NeoGeo_In.c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]
2020-02-13 Revert "Reporting correct pad id to LLAPI host"
    This reverts commit 4b047ea8b23090d3679b640455e2e45e9ea80044.
    [Genesis_In.c, LLIO.c, NeoGeo_In.c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]
2020-02-14 Corrected TG16 Avenue6 -> SNES mapping: IV V VI III II I -> L X R Y B A
    [TG16_In.c]
2020-03-03 Adding button mapping support
2020-03-04 Added LLOAD Mapping spreadsheet tool.
    [LLOAD Mapping.xlsx]
2020-03-04 Unfrozen spreadsheet panes
    [LLOAD Mapping.xlsx]
2020-03-05 Let us avoid duplicate code
    [main.c]
2020-03-07 Turned on O3 avr-gcc flag (speed optimization) for button mapper routine
2020-03-09 Map switching combo now takes in three buttons
    [LLOAD Mapping.xlsx]
2020-04-02 Start renaming project to LLAMA
    [LLAMA Mapping.xlsx]
2020-04-15 Latency measurements - Specify 1000Hz USB polling mode
2020-07-14 Disabled pull-ups for TG16/PCE controllers as those were interfering with the controller internal ones (6 button ones mainly). Also, decreased controller polling frequency.
    [TG16_In.c]

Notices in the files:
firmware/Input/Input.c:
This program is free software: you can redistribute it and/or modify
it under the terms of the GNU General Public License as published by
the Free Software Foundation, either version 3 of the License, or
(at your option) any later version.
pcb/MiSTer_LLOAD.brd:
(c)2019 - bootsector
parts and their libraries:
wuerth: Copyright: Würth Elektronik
